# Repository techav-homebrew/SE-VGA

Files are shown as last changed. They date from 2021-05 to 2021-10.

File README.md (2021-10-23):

# SE-VGA
Simple CPLD project to mirror the Mac SE video over VGA. The image is pixel-doubled to 1024x684 and displayed letterboxed (black borders) in a 1024x768 video frame. Device snoops writes to the frame buffer memory locations and caches the data to its own VRAM for display. Plugs into the PDS slot in a Mac SE, or plugs in place of the CPU on Mac SE, Plus, or 512k models (128k Mac could be made to work with some adjustment to the CPLD configuration, but is not a configuration supported by the memory selection jumpers). Tested and working on a Mac SE and a Mac Plus, both with 4MB of RAM.

Circuit uses a single AFT1508AS-7AX100 CPLD, a pair of 256kbit (32kx8) 15ns or faster SRAM, a 13MHz crystal with 5x clock multiplier for 65MHz pixel clock, along with some passives.

## Bill of Materials

| Qty | Manufacturer | Part No. | Name | Description |
|:---:|:---|:---|:---|:---|
|  2  | ISSI | IS61C256AL-12TLI | VRAM-ALT, VRAM-MAIN| 32kx8 12ns SRAM, TSOP-28 | 
|  1  | Microchip | ATF1508AS-7AX100 | LOGIC | ATF1508AS or EPM7128 CPLD, TQFP-100 |
|  1  | Renesas / IDT | 511MLF | CLK | Programmable Clock Multiplier, SO-8 |
|  1  | ECS | ECS-130-20-46X | XTAL | 13MHz Crystal, HC-46X or HC-49UP |
|  1  | TE Connectivity | 650473-5 | PDS | DIN 41612 Right-angle 3x32 pin male connector |
|  5  | | | C1, C2, C3, C4, C5 | 0.1uF Decoupling Capacitor, 0805 |
|  2  | | | C6, C7 | 10uF Electrolytic Capacitor |
|  2  | | | C8, C9 | 20pF Capacitor, 0805 |
|  2  | | | R3, R4, R5 | 10k pullup resistor, 0805 or axial |
|  3  | | | R2 | 460 ohm resistor, 0805 or axial |
|  3  | | | R1 | 75 ohm resistor, 0805 or axial |
|  1  | | | PGM | 2x5 pin header for CPLD JTAG programming |
|  1  | | | VGA | 2x5 pin header for VGA adapter |
|  1  | | | RAMSIZE | 3x2 jumper |
|  1  | | | BRD | 64-pin DIP header, male |
|  1  | | | CPU | 64-pin DIP socket, female |

## Frame Buffer Addressing

The Mac primary framebuffer starts at 0x5900 below the top of RAM. Since it's not in a static location for every system, the system's memory configuration is needed. This is set by three ramSize jumpers, which mask CPU address bits 21, 20, 19. Not all possible ramSize selections are valid memory sizes when using 30-pin SIMMs in the Mac SE. In theory, these combinations could be possible when using PDS memory expansion cards, but this is unlikely. The chart below indicates the valid & invalid ramSize configurations and the corresponding installed SIMM combinations.

|ramSize|Main Framebuffer|Alt Framebuffer|RAM Top Address + 1|RAM Size|Installed SIMMs |
|:-----:|:---:|:---:|:---:|:---:|---|
| 111 | 0x3fa700 | 0x3f2700 | 0x400000 | 4.0MB  | `[ 1MB 1MB ][ 1MB 1MB ]` |
| 110 | 0x37a700 | 0x372700 | 0x380000 | 3.5MB  | Invalid combination |
| 101 | 0x2fa700 | 0x2f2700 | 0x300000 | 3.0MB  | Invalid combination |
| 100 | 0x27a700 | 0x272700 | 0x280000 | 2.5MB  | `[ 1MB 1MB ][256kB 256kB]` |
| 011 | 0x1fa700 | 0x1f2700 | 0x200000 | 2.0MB  | `[ 1MB 1MB ][ --- --- ]` |
| 010 | 0x17a700 | 0x172700 | 0x180000 | 1.5MB  | Invalid combination |
| 001 | 0x0fa700 | 0x0f2700 | 0x100000 | 1.0MB  | `[256kB 256kB][256kB 256kB]` |
| 000 | 0x07a700 | 0x072700 | 0x080000 | 0.5MB  | `[256kB 256kB][ --- --- ]` |

## CPLD Pin Assignments

|signal|Direction|Pin|
|---|---|---|
|cpuAddr[23]|Input|PIN_100|
|cpuAddr[22]|Input|PIN_1|
|cpuAddr[21]|Input|PIN_2|
|cpuAddr[20]|Input|PIN_5|
|cpuAddr[19]|Input|PIN_6|
|cpuAddr[18]|Input|PIN_7|
|cpuAddr[17]|Input|PIN_8|
|cpuAddr[16]|Input|PIN_9|
|cpuAddr[15]|Input|PIN_10|
|cpuAddr[14]|Input|PIN_12|
|cpuAddr[13]|Input|PIN_13|
|cpuAddr[12]|Input|PIN_14|
|cpuAddr[11]|Input|PIN_16|
|cpuAddr[10]|Input|PIN_17|
|cpuAddr[9]|Input|PIN_19|
|cpuAddr[8]|Input|PIN_20|
|cpuAddr[7]|Input|PIN_21|
|cpuAddr[6]|Input|PIN_22|
|cpuAddr[5]|Input|PIN_23|
|cpuAddr[4]|Input|PIN_24|
|cpuAddr[3]|Input|PIN_25|
|cpuAddr[2]|Input|PIN_27|
|cpuAddr[1]|Input|PIN_28|
|cpuData[15]|Input|PIN_29|
|cpuData[14]|Input|PIN_30|
|cpuData[13]|Input|PIN_31|
|cpuData[12]|Input|PIN_32|
|cpuData[11]|Input|PIN_33|
|cpuData[10]|Input|PIN_35|
|cpuData[9]|Input|PIN_36|
|cpuData[8]|Input|PIN_37|
|cpuData[7]|Input|PIN_40|
|cpuData[6]|Input|PIN_41|
|cpuData[5]|Input|PIN_42|
|cpuData[4]|Input|PIN_44|
|cpuData[3]|Input|PIN_45|
|cpuData[2]|Input|PIN_46|
|cpuData[1]|Input|PIN_47|
|cpuData[0]|Input|PIN_48|
|cpuRnW|Input|PIN_96|
|nReset|Input|PIN_89|
|ncpuAS|Input|PIN_92|
|ncpuLDS|Input|PIN_93|
|ncpuUDS|Input|PIN_94|
|nhSync|Output|PIN_85|
|nvSync|Output|PIN_84|
|nvramCE0|Output|PIN_81|
|nvramCE1|Output|PIN_80|
|nvramOE|Output|PIN_79|
|nvramWE|Output|PIN_78|
|pixClk|Input|PIN_87|
|ramSize[2]|Input|PIN_97|
|ramSize[1]|Input|PIN_98|
|ramSize[0]|Input|PIN_99|
|vidOut|Output|PIN_83|
|vramAddr[14]|Output|PIN_77|
|vramAddr[13]|Output|PIN_76|
|vramAddr[12]|Output|PIN_75|
|vramAddr[11]|Output|PIN_72|
|vramAddr[10]|Output|PIN_71|
|vramAddr[9]|Output|PIN_70|
|vramAddr[8]|Output|PIN_69|
|vramAddr[7]|Output|PIN_68|
|vramAddr[6]|Output|PIN_67|
|vramAddr[5]|Output|PIN_65|
|vramAddr[4]|Output|PIN_64|
|vramAddr[3]|Output|PIN_63|
|vramAddr[2]|Output|PIN_61|
|vramAddr[1]|Output|PIN_60|
|vramAddr[0]|Output|PIN_58|
|vramData[7]|Bidir|PIN_57|
|vramData[6]|Bidir|PIN_56|
|vramData[5]|Bidir|PIN_55|
|vramData[4]|Bidir|PIN_54|
|vramData[3]|Bidir|PIN_53|
|vramData[2]|Bidir|PIN_52|
|vramData[1]|Bidir|PIN_50|
|vramData[0]|Bidir|PIN_49|
|TCK|Input|PIN_62|
|TDI|Input|PIN_4|
|TDO|Output|PIN_73|
|TMS|Input|PIN_15

## Known Issues
- ~~First run schematic and gerbers used three pairs of resistor dividers for R, G, B output channels. A better approach would be to use a single divider and tie all three output channels together. Also 470 ohm is a bit too high, so the image is quite dark.~~ Removed extraneous resistor dividers. Changed 470ohm resistor to 460.
- ~~The resistor footprints are too small for 1/4W parts. Might work with 1/8W parts.~~ Added footprints for 0805 resistors. 
- ~~Timing for the SE window is a bit off. It appears to be starting the window a couple pixels early on the left, and it might be cutting off the last pixel or two on the right.~~
- The ninth vertical line is missing from the output image, and there is a black line two pixels from the right side of the screen.
- There is still a timing issue with VRAM writes. Some writes seem to get missed.
- Additional decoupling is needed when using the board in 512k/Plus Macs. Without decoupling on every VCC pin of the CPLD and decoupling for the 68000 CPU, overall system stability is severely impacted. 
- Support for alternate frame buffer is currently disabled.

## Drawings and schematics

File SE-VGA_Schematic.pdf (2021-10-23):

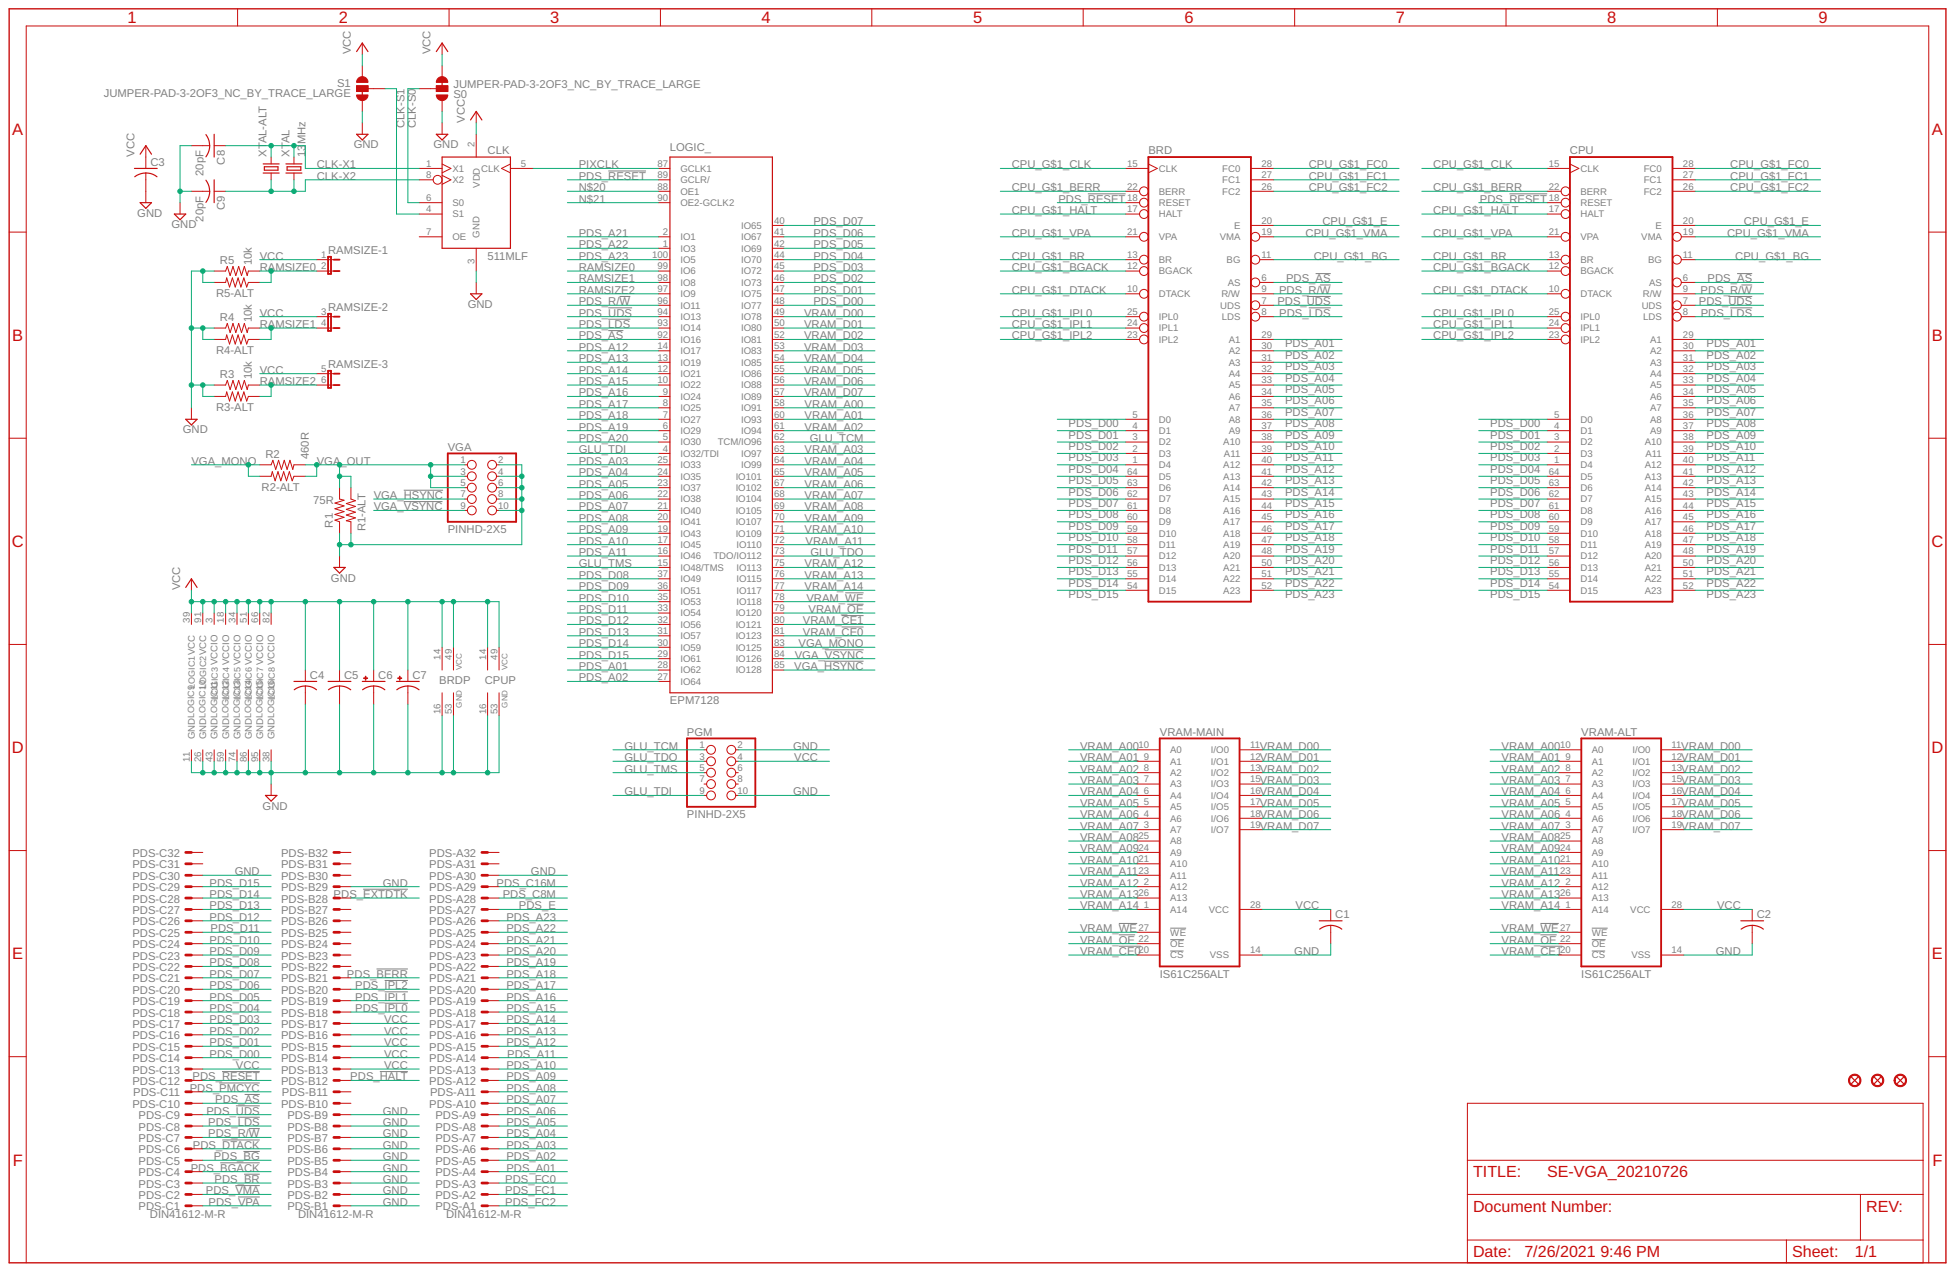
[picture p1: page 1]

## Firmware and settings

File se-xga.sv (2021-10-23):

/******************************************************************************
 * SE-VGA
 * Top-level module 
 * techav
 * 2021-10-12
 ******************************************************************************
 * This is ... mostly working. It has some write glitches and a vertical line
 * five pixels from the left side of the screen.
 *****************************************************************************/

module sevga (
    input wire              nReset,     // System reset signal
    input wire              pixClk,     // 65MHz pixel clock
    output wire             nhSync,     // HSync signal
    output wire             nvSync,     // VSync signal
    output wire             vidOut,     // 1-bit Monochrome video signal

    output logic [14:0]     vramAddr,   // VRAM Address bus
    inout logic [7:0]       vramData,   // VRAM Data bus
    output wire             nvramOE,    // VRAM Read strobe
    output wire             nvramWE,    // VRAM Write strobe
    output wire             nvramCE0,   // VRAM Main chip select signal
    output wire             nvramCE1,   // VRAM Alt chip select signal

    input logic [23:1]      cpuAddr,    // CPU Address bus
    input logic [15:0]      cpuData,    // CPU Data bus
    input wire              ncpuAS,     // CPU Address Strobe signal
    input wire              ncpuUDS,    // CPU Upper Data Strobe signal
    input wire              ncpuLDS,    // CPU Lower Data Strobe signal
    input wire              cpuRnW,     // CPU Read/Write select signal
    input logic [2:0]       ramSize     // Select installed RAM size
);

/******************************************************************************
 * Initial Video Signal Timing
 * The following four functions establish the basic XGA signal timing and 
 * assert the horizontal and vertical sync signals as appropriate.
 * These functions are the minimum required for a signal presence detect test.
 *****************************************************************************/
logic [10:0] hCount;    // 0..1343
logic [9:0] vCount;     // 0..805
wire nhSyncInner;

// Primary video sync counters -- Now more synchronous!
always @(negedge pixClk) begin
    if(hCount < 11'd1343) hCount <= hCount + 11'd1;
    else begin
        hCount <= 11'd0;
        if(vCount < 10'd805) vCount <= vCount + 10'd1;
        else vCount <= 10'd0;
    end
end

// horizontal and vertical sync signals
always_comb begin
    //if(hCount >= 11'd1048 && hCount < 11'd1184) nhSyncInner <= 0;
    if(hCount >= 11'd1052 && hCount < 11'd1187) nhSyncInner <= 0;
    else nhSyncInner <= 1;
    nhSync <= nhSyncInner;

    if(vCount >= 10'd729 && vCount < 10'd735) nvSync <= 0;
    else nvSync <= 1;
end

/******************************************************************************
 * Useful signals
 * Here we break out a few useful signals, derived from the timing above, that
 * will help us elsewhere.
 *****************************************************************************/
wire hActive, vActive;      // active video signals. vidout black when negated
wire vidActive;             // active when both hActive and vActive asserted
wire hLoad;                 // load pixel data from vram when asserted

assign vidActive = hActive & vActive;

always_comb begin
    if(hCount >= 3 && hCount < 1027) hActive <= 1;
    else hActive <= 0;

    if(vCount >= 0 && vCount < 684) vActive <= 1;
    else vActive <= 0;

    if(hCount >= 0 && hCount < 1024 && vActive) hLoad <= 1;
    else hLoad <= 0;
end

/******************************************************************************
 * Primary State Machine
 * This is the primary state machine which runs the entire system, handling
 * VRAM reads, VRAM writes, VIA writes, and idle states
 *****************************************************************************/

// used to align primary state machine with horizontal counter
wire [3:0] vSeq = hCount[3:0];

// define state machine states (Gray code)
parameter
    S0  =   4'b0000,    // VRAM Read 0
    S1  =   4'b0001,    // VRAM Read 1
    S2  =   4'b0011,    // Idle
    S3  =   4'b0010,    // VRAM Write Upper 0
    S4  =   4'b0110,    // VRAM Write Upper 1
    S5  =   4'b0111,    // VRAM Write Lower 0
    S6  =   4'b0101,    // VRAM Write Lower 1
    S7  =   4'b0100,    // VIA Write
    S8  =   4'b1100,    // VSync (to be added later)
    S9  =   4'b1101,    // undefined
    S10 =   4'b1111,    // undefined
    S11 =   4'b1110,    // undefined
    S12 =   4'b1010,    // undefined
    S13 =   4'b1011,    // undefined
    S14 =   4'b1001,    // undefined
    S15 =   4'b1000;    // undefined

logic [3:0] pState;

// And here is the much simplified primary state machine
always @(negedge pixClk or negedge nReset) begin
    if(!nReset) pState <= S2;   // resync on reset by jumping to idle state
    else begin
        case(pState)
            S0: pState <= S1;   // first VRAM read state, always move to S1
            S3: pState <= S4;   // first UDS write state, always move to S4
            S5: pState <= S6;   // first LDS write state, always move to S6
            /*S7: begin
                
                pState <= S2;
            end*/
            S2: begin
                // here is where everything actually happens.
                if(vSeq == 4'hF) pState <= S0;   // time for a read state
                else if(cpuUWriteReq && !cpuUWriteSrv && vSeq < 4'hD) pState <= S3;
                else if(cpuLWriteReq && !cpuLWriteSrv && vSeq < 4'hD) pState <= S5;
                else if(cpuVIAReq    && !cpuVIASrv    && vSeq < 4'hE) pState <= S7;
                else pState <= S2;
            end
            default: pState <= S2; // everyone ends up at S2 (idle)
        endcase
    end
end
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

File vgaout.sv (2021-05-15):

/******************************************************************************
 * SE-VGA
 * VGA video output
 * techav
 * 2021-04-06
 ******************************************************************************
 * Fetches video data from VRAM and shifts out
 *****************************************************************************/

`include "vgashiftout.sv"

module vgaout (
    input wire          pixClock,
    input wire          nReset,
    input logic [9:0]   hCount,
    input logic [9:0]   vCount,
    input wire          hSEActive,
    input wire          vSEActive,
    input logic [7:0]   vramData,
    output logic [14:0] vramAddr,
    output wire         nvramOE,
    output wire         vidOut
);

wire vidMuxOut; // pixel data shift out
wire vidActive; // combined active video signal

wire nVidLoad;  // Load VRAM data into shifter
vgaShiftOut vOut(
    .nReset(nReset),
    .clk(pixClock),
    .nLoad(nVidLoad),
    .parIn(vramData),
    .out(vidMuxOut)
);

always_comb begin
    if(hCount[2:0] == 0) nVidLoad <= 0;
    else nVidLoad <= 1;

    // combined video active signal
    if(hSEActive == 1'b1 && vSEActive == 1'b1) begin
        vidActive <= 1'b1;
    end else begin
        vidActive <= 1'b0;
    end

    // video data output
    if(vidActive == 1'b1) begin
        vidOut <= ~vidMuxOut;
    end else begin
        vidOut <= 1'b0;
    end

    // vram read signal
    if(vidActive == 1'b1 && hCount[2:0] == 0) begin
        nvramOE <= 1'b0;
    end else begin
        nvramOE <= 1'b1;
    end

    // vram address signals
    // these will be mux'd with cpu addresses externally
    vramAddr[14:6] <= vCount[8:0];
    vramAddr[5:0]  <= hCount[8:3];
end
    
endmodule

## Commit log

2021-04-13 New output stage
2021-04-20 Add Alternate Frame Buffer Support
2021-04-20 Pin Assignments
2021-05-22 Add Gerbers
    [copper_bottom.gbr, copper_top.gbr, drill_1_16.xln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]
2021-07-25 XGA Board Rev
    Rework of board to add support for pixel-doubled image on XGA resolution frame, and installation in Plus or 512k
    [copper_bottom.gbr, copper_top.gbr, drill_1_16.xln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]
2021-07-27 Change multiplier part
    Changed 512MLF to 511MLF due to EOL
    [copper_bottom.gbr, copper_top.gbr, drill_1_16.xln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]
2021-08-05 Start logic rebuild for XGA
    Ground-up rewrite of the video timing and output logic for XGA. Much simpler than the initial VGA logic. First draft, incomplete.
2021-10-13 Fixed image overwrite issues
    [se-xga.sv]
